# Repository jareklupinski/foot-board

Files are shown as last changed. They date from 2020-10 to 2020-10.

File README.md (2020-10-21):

# foot-board
A USB Keyboard Device, laid out to be used with your Feet

Uses Kailh Low Profile Switches, code written to be easy to jump into and modify.

Can be produced by JLCPCB for extremely low cost. Only thing they cannot do is solder the MicroUSB jack; considering laying out the PCB with a connector for an off-the-shelf Blue Pill board to fix.

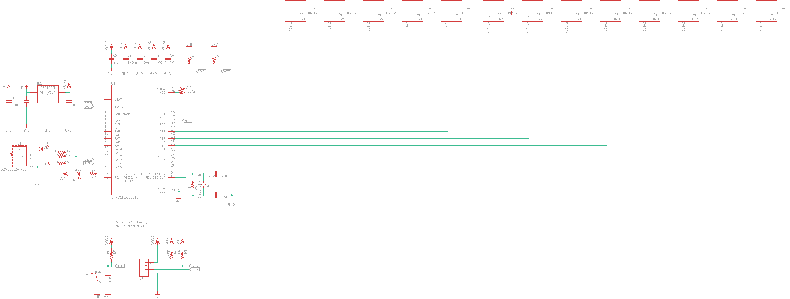
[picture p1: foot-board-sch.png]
schematic

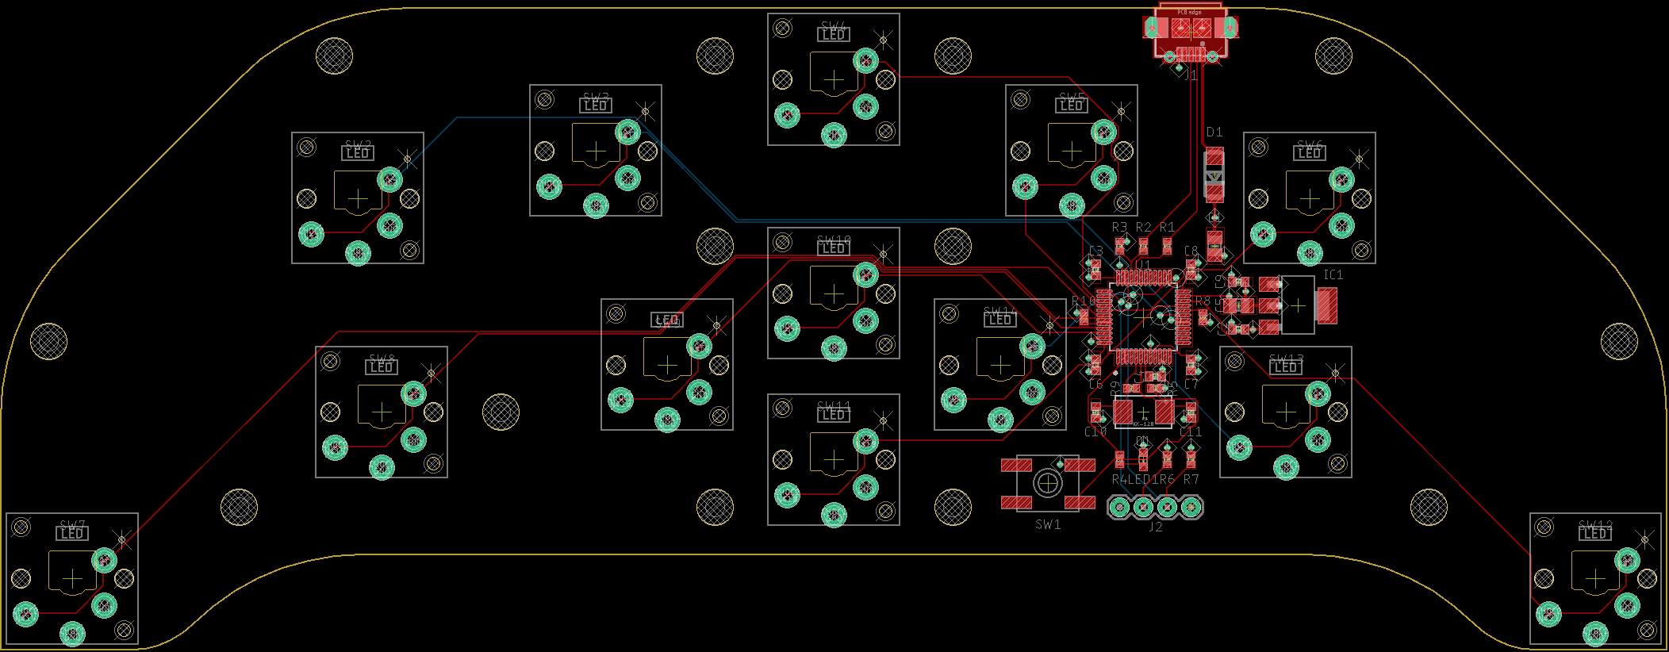
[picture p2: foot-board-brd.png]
board

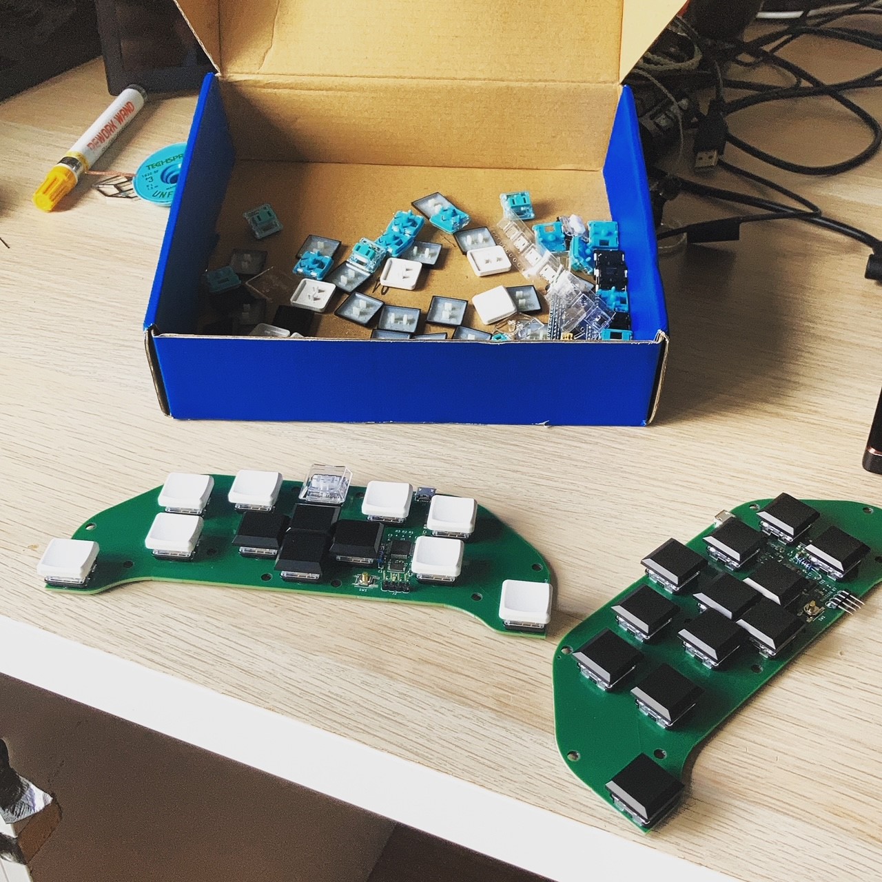
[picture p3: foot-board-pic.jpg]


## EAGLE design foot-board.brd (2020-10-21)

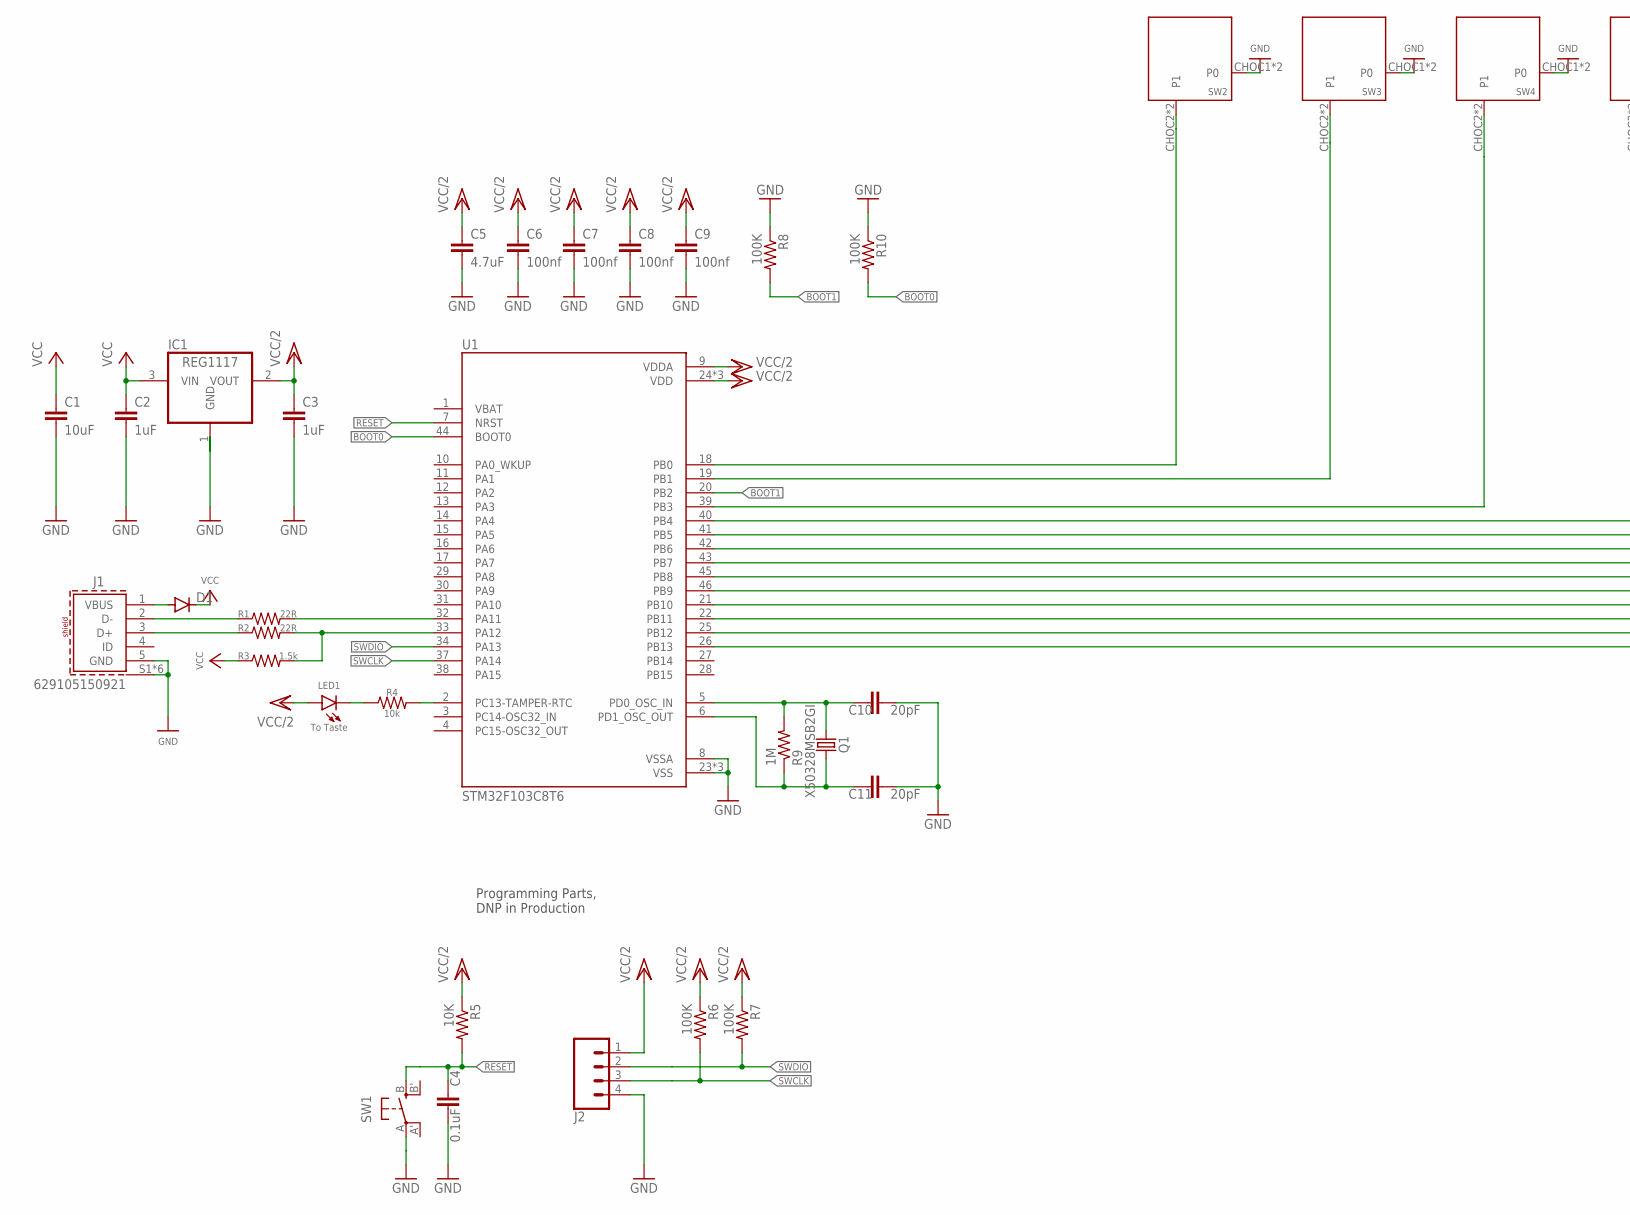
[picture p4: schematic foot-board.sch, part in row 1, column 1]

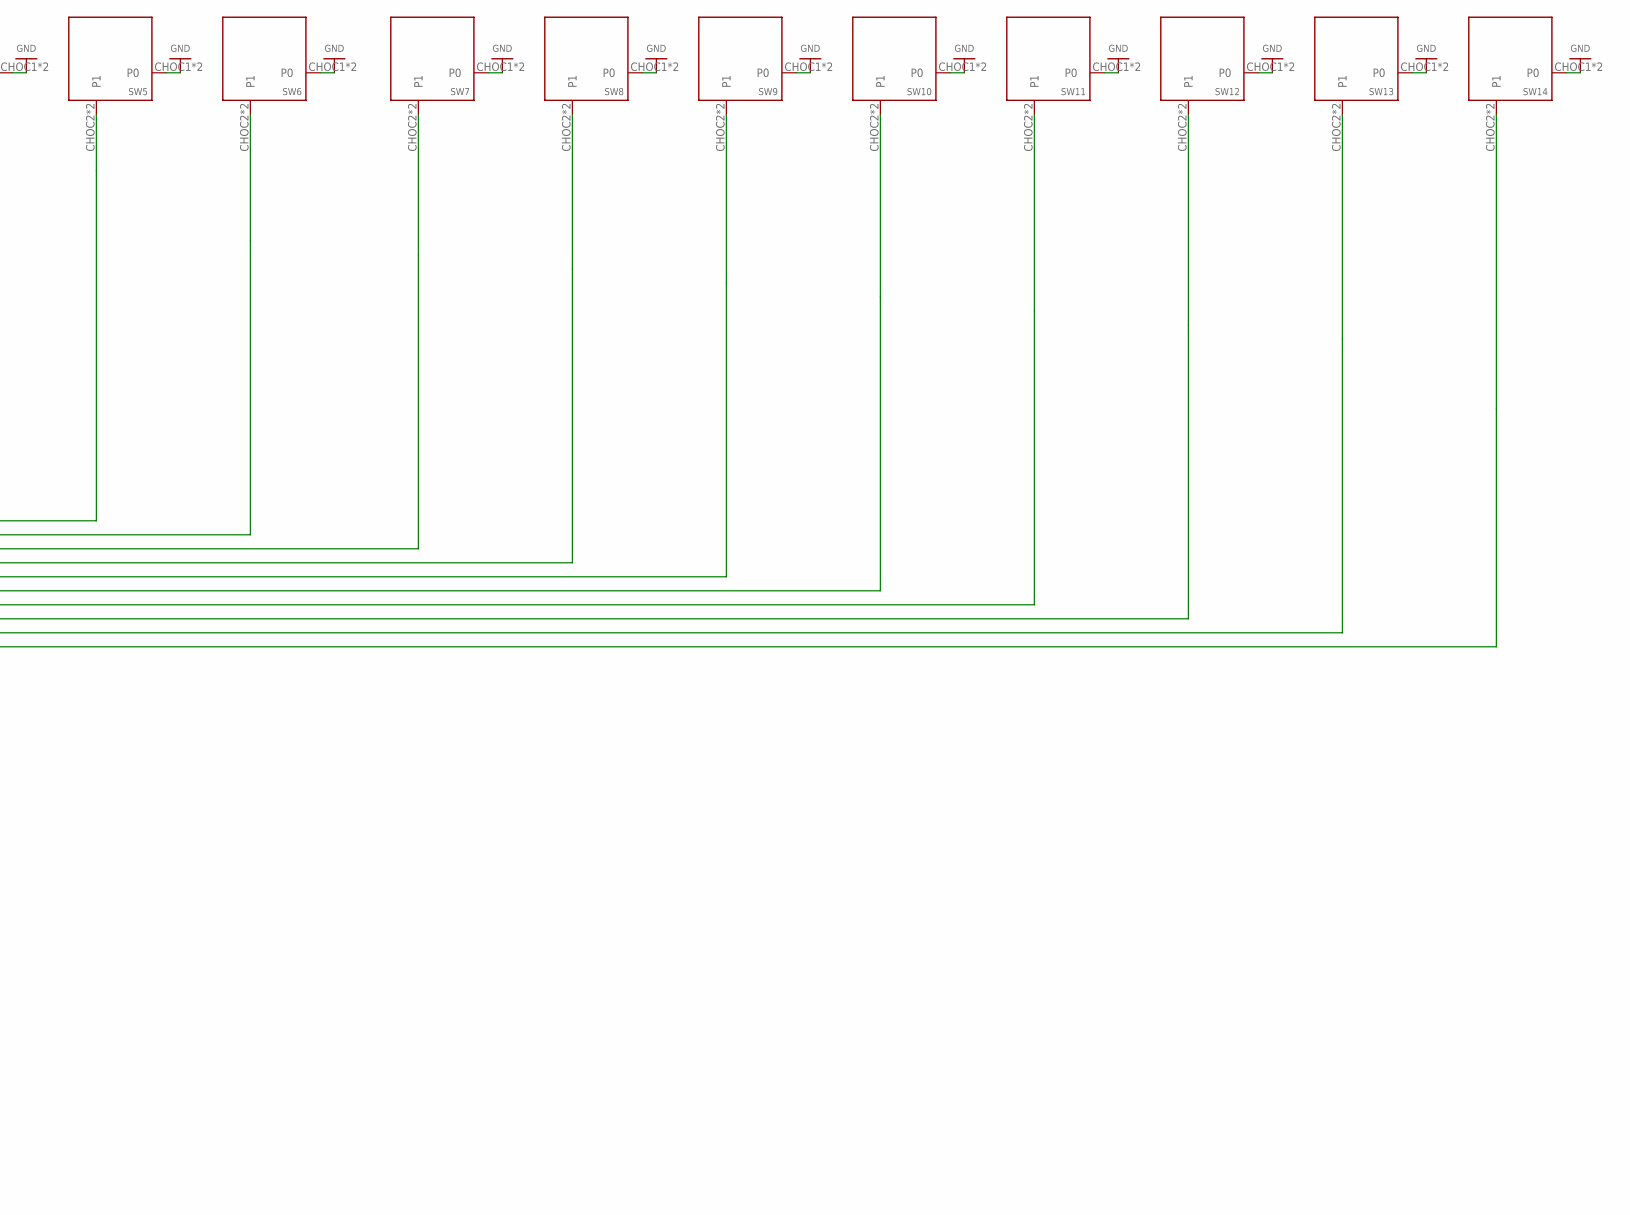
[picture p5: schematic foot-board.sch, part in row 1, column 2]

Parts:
C1: 10uF; C0805
C2, C3: 1uF; C0402
C4: 0.1uF; C0402
C5: 4.7uF; C0805
C6, C7, C8, C9: 100nf; C0402
C10, C11: 20pF; C0402
D1: DIODE-DO214AC; DO214AC
IC1: REG1117; SOT223
J1: 629105150921
J2: CONN_04; 1X04
LED1: To Taste; CHIPLED_0603
Q1: X50328MSB2GI; 6.0X3.5_2
R1, R2: 22R; R0402
R3: 1.5k; R0402
R4: 10k; R0402
R5: 10K; R0402
R6, R7, R8, R10: 100K; R0402
R9: 1M; R0402
SW1: SPST_TACT-EVQQ2; EVQ-Q2
SW2, SW3, SW4, SW5, SW6, SW7, SW8, SW9, SW10, SW11, SW12, SW13, SW14: KEYSWITCH-PLAIN-CHOCX-1U; CHOCX-1U
U1: STM32F103C8T6; QFP50P900X900X160-48N

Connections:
BOOT0: R10.2, U1.44 (BOOT0)
BOOT1: R8.2, U1.20 (PB2)
GND: C1.2, C2.2, C3.2, C4.2, C5.2, C6.2, C7.2, C8.2, C9.2, C10.2, C11.2, IC1.1 (GND), J1.5 (GND), J1.S1 (SHIELD), J1.S2 (SHIELD), J1.S3 (SHIELD), J1.S4 (SHIELD), J1.S5 (SHIELD), J1.S6 (SHIELD), J2.4, R8.1, R10.1, SW1.A, SW2.CHOC1 (P0), SW2.X1 (P0), SW3.CHOC1 (P0), SW3.X1 (P0), SW4.CHOC1 (P0), SW4.X1 (P0), SW5.CHOC1 (P0), SW5.X1 (P0), SW6.CHOC1 (P0), SW6.X1 (P0), SW7.CHOC1 (P0), SW7.X1 (P0), SW8.CHOC1 (P0), SW8.X1 (P0), SW9.CHOC1 (P0), SW9.X1 (P0), SW10.CHOC1 (P0), SW10.X1 (P0), SW11.CHOC1 (P0), SW11.X1 (P0), SW12.CHOC1 (P0), SW12.X1 (P0), SW13.CHOC1 (P0), SW13.X1 (P0), SW14.CHOC1 (P0), SW14.X1 (P0), U1.8 (VSSA), U1.23 (VSS), U1.35 (VSS), U1.47 (VSS)
unnamed: R4.2, U1.2 (PC13-TAMPER-RTC)
unnamed: LED1.C, R4.1
unnamed: SW2.CHOC2 (P1), SW2.X2 (P1), U1.18 (PB0)
unnamed: R1.2, U1.32 (PA11)
unnamed: D1.A, J1.1 (VBUS)
unnamed: R2.2, R3.2, U1.33 (PA12)
unnamed: SW3.CHOC2 (P1), SW3.X2 (P1), U1.19 (PB1)
unnamed: SW4.CHOC2 (P1), SW4.X2 (P1), U1.39 (PB3)
unnamed: SW5.CHOC2 (P1), SW5.X2 (P1), U1.40 (PB4)
unnamed: SW6.CHOC2 (P1), SW6.X2 (P1), U1.41 (PB5)
unnamed: SW7.CHOC2 (P1), SW7.X2 (P1), U1.42 (PB6)
unnamed: SW8.CHOC2 (P1), SW8.X2 (P1), U1.43 (PB7)
unnamed: SW9.CHOC2 (P1), SW9.X2 (P1), U1.45 (PB8)
unnamed: SW10.CHOC2 (P1), SW10.X2 (P1), U1.46 (PB9)
unnamed: SW11.CHOC2 (P1), SW11.X2 (P1), U1.21 (PB10)
unnamed: J1.2 (D-), R1.1
unnamed: J1.3 (D+), R2.1
unnamed: SW12.CHOC2 (P1), SW12.X2 (P1), U1.22 (PB11)
unnamed: SW13.CHOC2 (P1), SW13.X2 (P1), U1.25 (PB12)
unnamed: SW14.CHOC2 (P1), SW14.X2 (P1), U1.26 (PB13)
unnamed: C10.1, Q1.2, R9.2, U1.5 (PD0_OSC_IN)
unnamed: C11.1, Q1.1, R9.1, U1.6 (PD1_OSC_OUT)
RESET: C4.1, R5.2, SW1.B (S), U1.7 (NRST)
SWCLK: J2.3, R6.2, U1.37 (PA14)
SWDIO: J2.2, R7.2, U1.34 (PA13)
VCC: C1.1, C2.1, D1.C, IC1.3 (VIN), R3.1
VCC/2: C3.1, C5.1, C6.1, C7.1, C8.1, C9.1, IC1.2 (VOUT), J2.1, LED1.A, R5.1, R6.1, R7.1, U1.9 (VDDA), U1.24 (VDD), U1.36 (VDD), U1.48 (VDD)

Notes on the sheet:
Programming Parts, DNP in Production

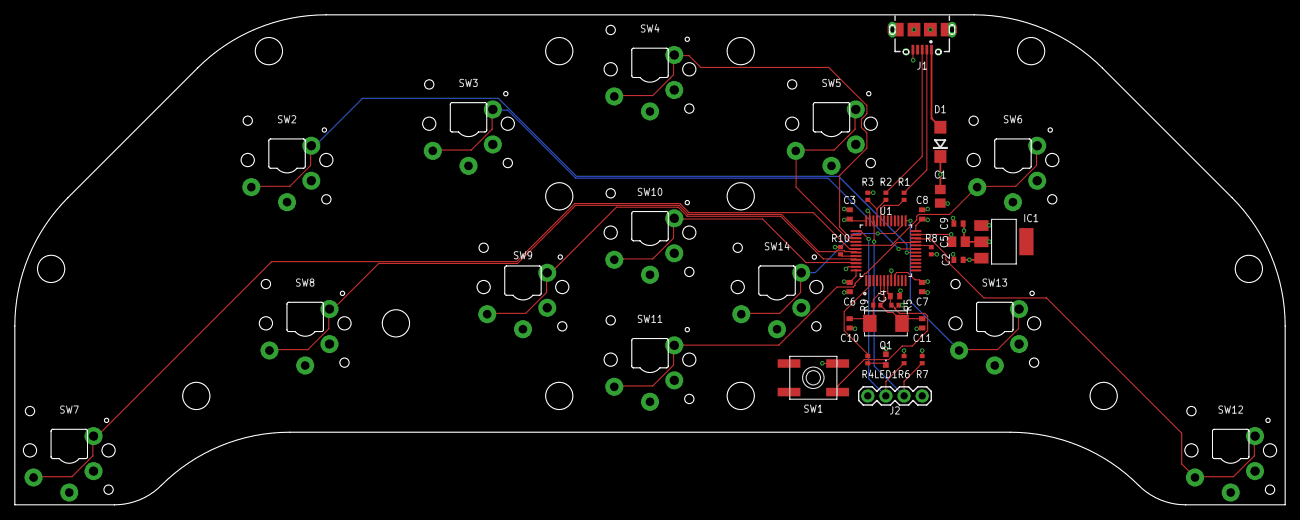
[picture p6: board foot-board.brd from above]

Board: 4 copper layers, 177.8 x 68.6 mm, 42 parts (0 on the bottom side), 30 nets.

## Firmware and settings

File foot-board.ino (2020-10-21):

#include "Keyboard.h"

void setup() {
  pinMode(PB0, INPUT_PULLUP);
  pinMode(PB1, INPUT_PULLUP);
  pinMode(PB3, INPUT_PULLUP);
  pinMode(PB4, INPUT_PULLUP);
  pinMode(PB5, INPUT_PULLUP);
  pinMode(PB6, INPUT_PULLUP);
  pinMode(PB7, INPUT_PULLUP);
  pinMode(PB8, INPUT_PULLUP);
  pinMode(PB9, INPUT_PULLUP);
  pinMode(PB10, INPUT_PULLUP);
  pinMode(PB11, INPUT_PULLUP);
  pinMode(PB12, INPUT_PULLUP);
  pinMode(PB13, INPUT_PULLUP);
  pinMode(PC13, OUTPUT);
  Keyboard.begin();
  digitalWrite(PC13, LOW);
}

byte button1Pressed = 0;
byte button2Pressed = 0;
byte button3Pressed = 0;
byte button4Pressed = 0;
byte button5Pressed = 0;
byte button6Pressed = 0;
byte button7Pressed = 0;
byte button8Pressed = 0;
byte button9Pressed = 0;
byte button10Pressed = 0;
byte button11Pressed = 0;
byte button12Pressed = 0;
byte button13Pressed = 0;

void loop() {
  byte newButton1Pressed = 0;
  if ( digitalReadFast(PB_0) ) newButton1Pressed = 1;
  if ( newButton1Pressed != button1Pressed ) {
    newButton1Pressed ? Keyboard.release('1') : Keyboard.press('1');
    button1Pressed = newButton1Pressed;
  }
  byte newButton2Pressed = 0;
  if ( digitalReadFast(PB_1) ) newButton2Pressed = 1;
  if ( newButton2Pressed != button2Pressed ) {
    newButton2Pressed ? Keyboard.release('2') : Keyboard.press('2');
    button2Pressed = newButton2Pressed;
  }
  byte newButton3Pressed = 0;
  if ( digitalReadFast(PB_3) ) newButton3Pressed = 1;
  if ( newButton3Pressed != button3Pressed ) {
    newButton3Pressed ? Keyboard.release('3') : Keyboard.press('3');
    button3Pressed = newButton3Pressed;
  }
  byte newButton4Pressed = 0;
  if ( digitalReadFast(PB_4) ) newButton4Pressed = 1;
  if ( newButton4Pressed != button4Pressed ) {
    newButton4Pressed ? Keyboard.release('4') : Keyboard.press('4');
    button4Pressed = newButton4Pressed;
  }
  byte newButton5Pressed = 0;
  if ( digitalReadFast(PB_5) ) newButton5Pressed = 1;
  if ( newButton5Pressed != button5Pressed ) {
    newButton5Pressed ? Keyboard.release('5') : Keyboard.press('5');
    button5Pressed = newButton5Pressed;
  }
  byte newButton6Pressed = 0;
  if ( digitalReadFast(PB_6) ) newButton6Pressed = 1;
  if ( newButton6Pressed != button6Pressed ) {
    newButton6Pressed ? Keyboard.release('z') : Keyboard.press('z');
    button6Pressed = newButton6Pressed;
  }
  byte newButton7Pressed = 0;
  if ( digitalReadFast(PB_7) ) newButton7Pressed = 1;
  if ( newButton7Pressed != button7Pressed ) {
    newButton7Pressed ? Keyboard.release('x') : Keyboard.press('x');
    button7Pressed = newButton7Pressed;
  }
  byte newButton8Pressed = 0;
  if ( digitalReadFast(PB_8) ) newButton8Pressed = 1;
  if ( newButton8Pressed != button8Pressed ) {
    newButton8Pressed ? Keyboard.release(KEY_LEFT_ARROW) : Keyboard.press(KEY_LEFT_ARROW);
    button8Pressed = newButton8Pressed;
  }
  byte newButton9Pressed = 0;
  if ( digitalReadFast(PB_9) ) newButton9Pressed = 1;
  if ( newButton9Pressed != button9Pressed ) {
    newButton9Pressed ? Keyboard.release(KEY_UP_ARROW) : Keyboard.press(KEY_UP_ARROW);
    button9Pressed = newButton9Pressed;
  }
  byte newButton10Pressed = 0;
  if ( digitalReadFast(PB_10) ) newButton10Pressed = 1;
  if ( newButton10Pressed != button10Pressed ) {
    newButton10Pressed ? Keyboard.release(KEY_DOWN_ARROW) : Keyboard.press(KEY_DOWN_ARROW);
    button10Pressed = newButton10Pressed;
  }
  byte newButton11Pressed = 0;
  if ( digitalReadFast(PB_11) ) newButton11Pressed = 1;
  if ( newButton11Pressed != button11Pressed ) {
    newButton11Pressed ? Keyboard.release('m') : Keyboard.press('m');
    button11Pressed = newButton11Pressed;
  }
  byte newButton12Pressed = 0;
  if ( digitalReadFast(PB_12) ) newButton12Pressed = 1;
  if ( newButton12Pressed != button12Pressed ) {
    newButton12Pressed ? Keyboard.release('n') : Keyboard.press('n');
    button12Pressed = newButton12Pressed;
  }
  byte newButton13Pressed = 0;
  if ( digitalReadFast(PB_13) ) newButton13Pressed = 1;
  if ( newButton13Pressed != button13Pressed ) {
    newButton13Pressed ? Keyboard.release(KEY_RIGHT_ARROW) : Keyboard.press(KEY_RIGHT_ARROW);
    button13Pressed = newButton13Pressed;
  }
}

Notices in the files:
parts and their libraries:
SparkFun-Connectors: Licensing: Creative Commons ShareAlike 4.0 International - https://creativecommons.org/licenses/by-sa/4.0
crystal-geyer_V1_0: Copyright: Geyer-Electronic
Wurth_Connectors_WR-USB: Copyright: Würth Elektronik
